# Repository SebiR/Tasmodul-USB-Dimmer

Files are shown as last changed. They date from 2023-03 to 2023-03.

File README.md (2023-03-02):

# Tasmodul USB-Dimmer
A plug-in dimmer for USB powered lamps and lights to be used with Tasmota, WLED or custom ESP8266 firmwares.

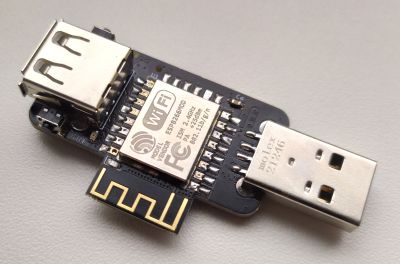
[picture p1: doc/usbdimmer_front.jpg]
Front


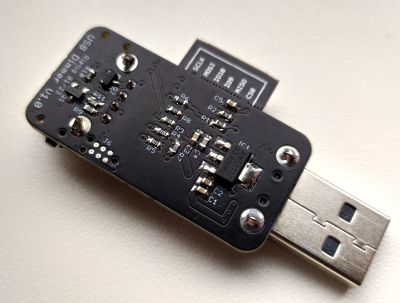
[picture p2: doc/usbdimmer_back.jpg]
Back


## Features
* Small formfactor (21x42mm without USB)
* Up to 2A output current (approx.)
* 2 buttons for user interfacing

## Configuration
* GPIO4: Inverted PWM output (or switch)
* GPIO5: Inverted push button "DOWN"
* GPIO13: Inverted push button "UP"
* GPIO0: Inverted LED indicator

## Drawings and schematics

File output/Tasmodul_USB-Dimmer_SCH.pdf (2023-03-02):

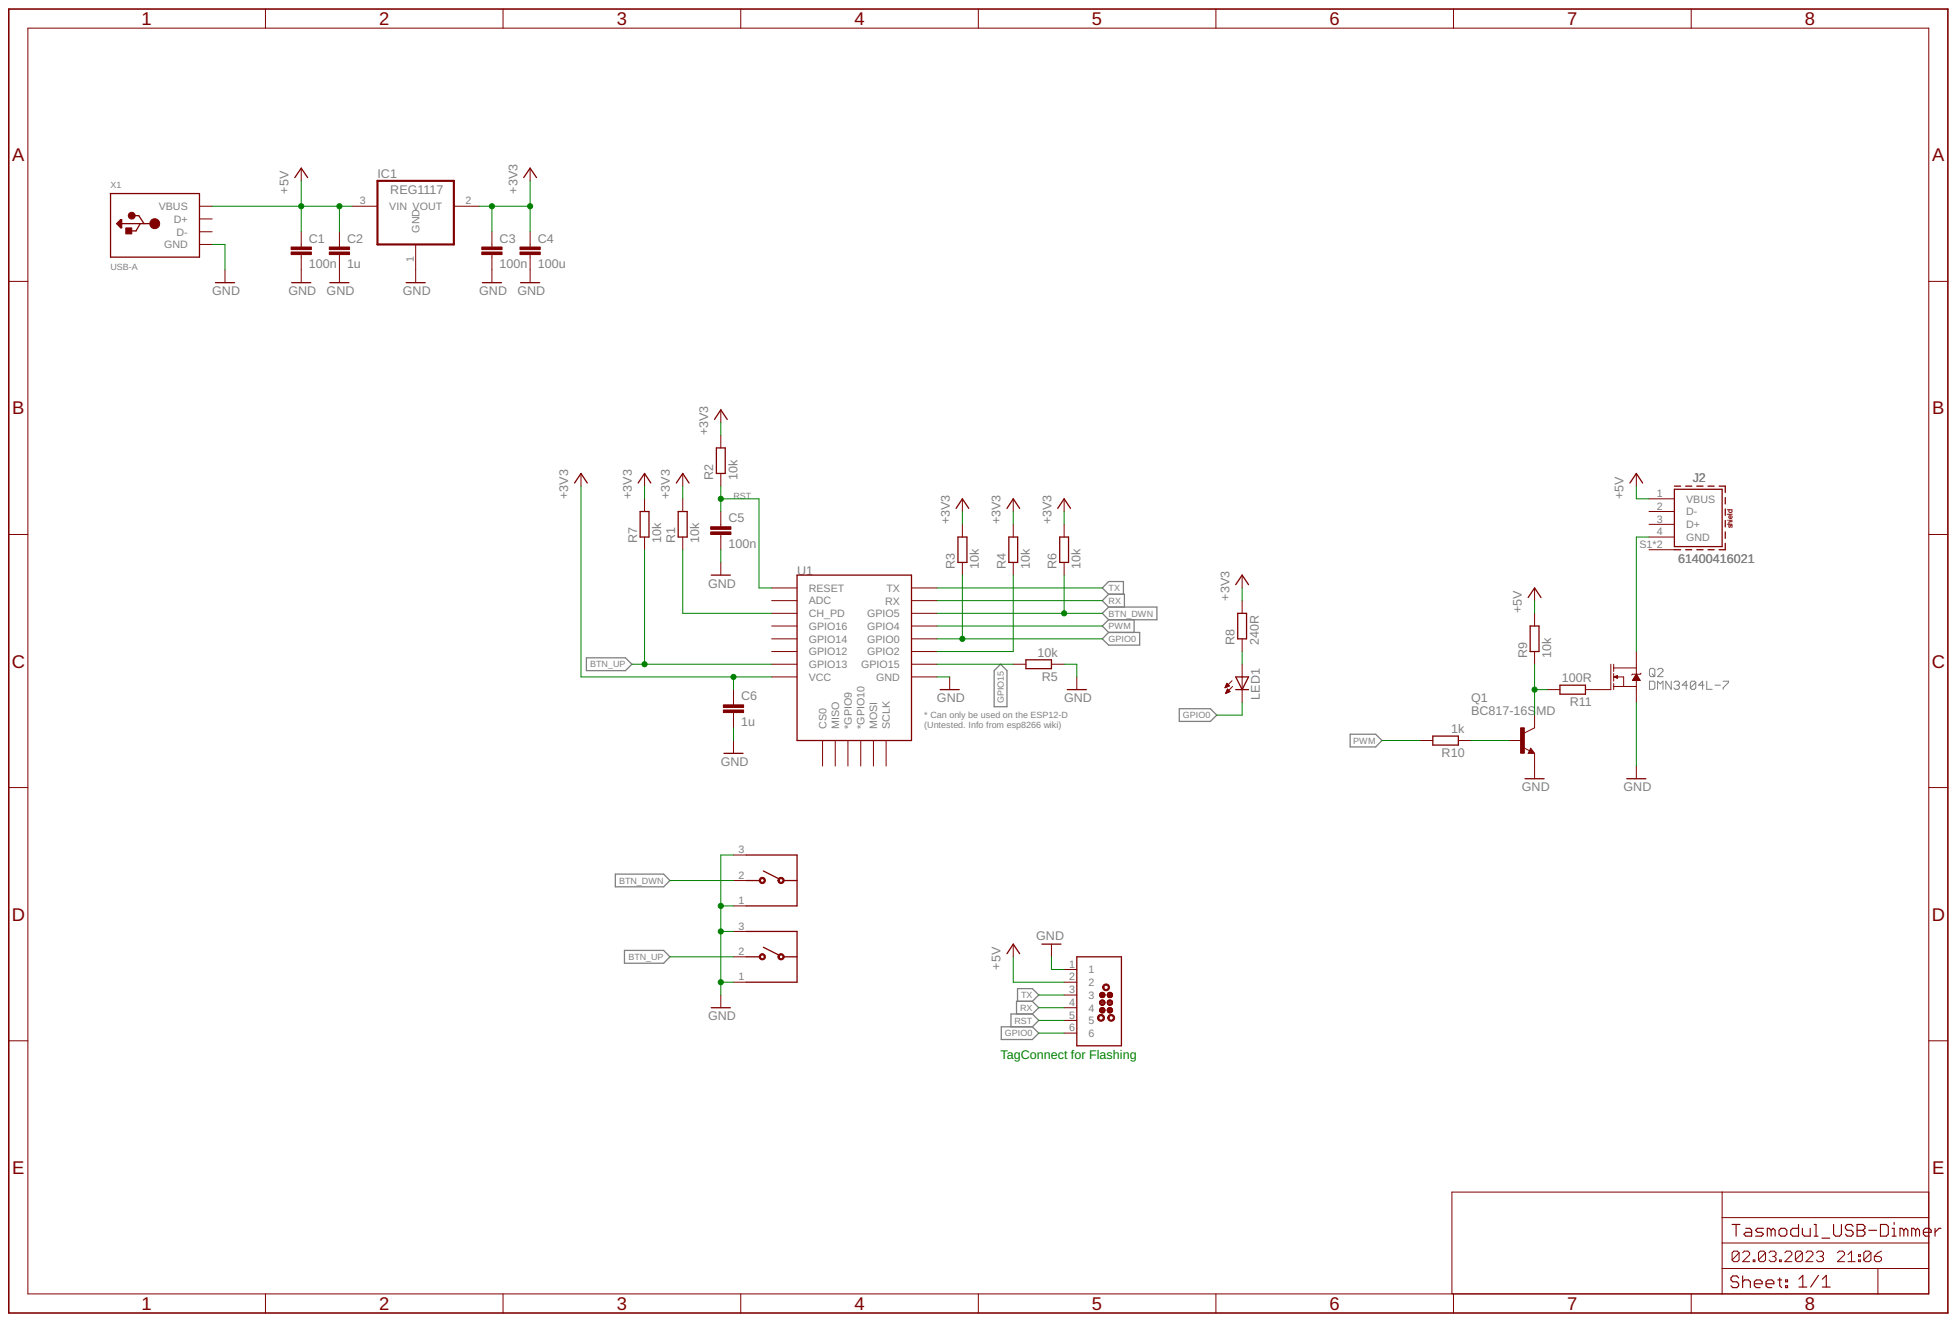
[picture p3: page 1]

* Can only be used on the ESP12-D
(Untested. Info from esp8266 wiki)

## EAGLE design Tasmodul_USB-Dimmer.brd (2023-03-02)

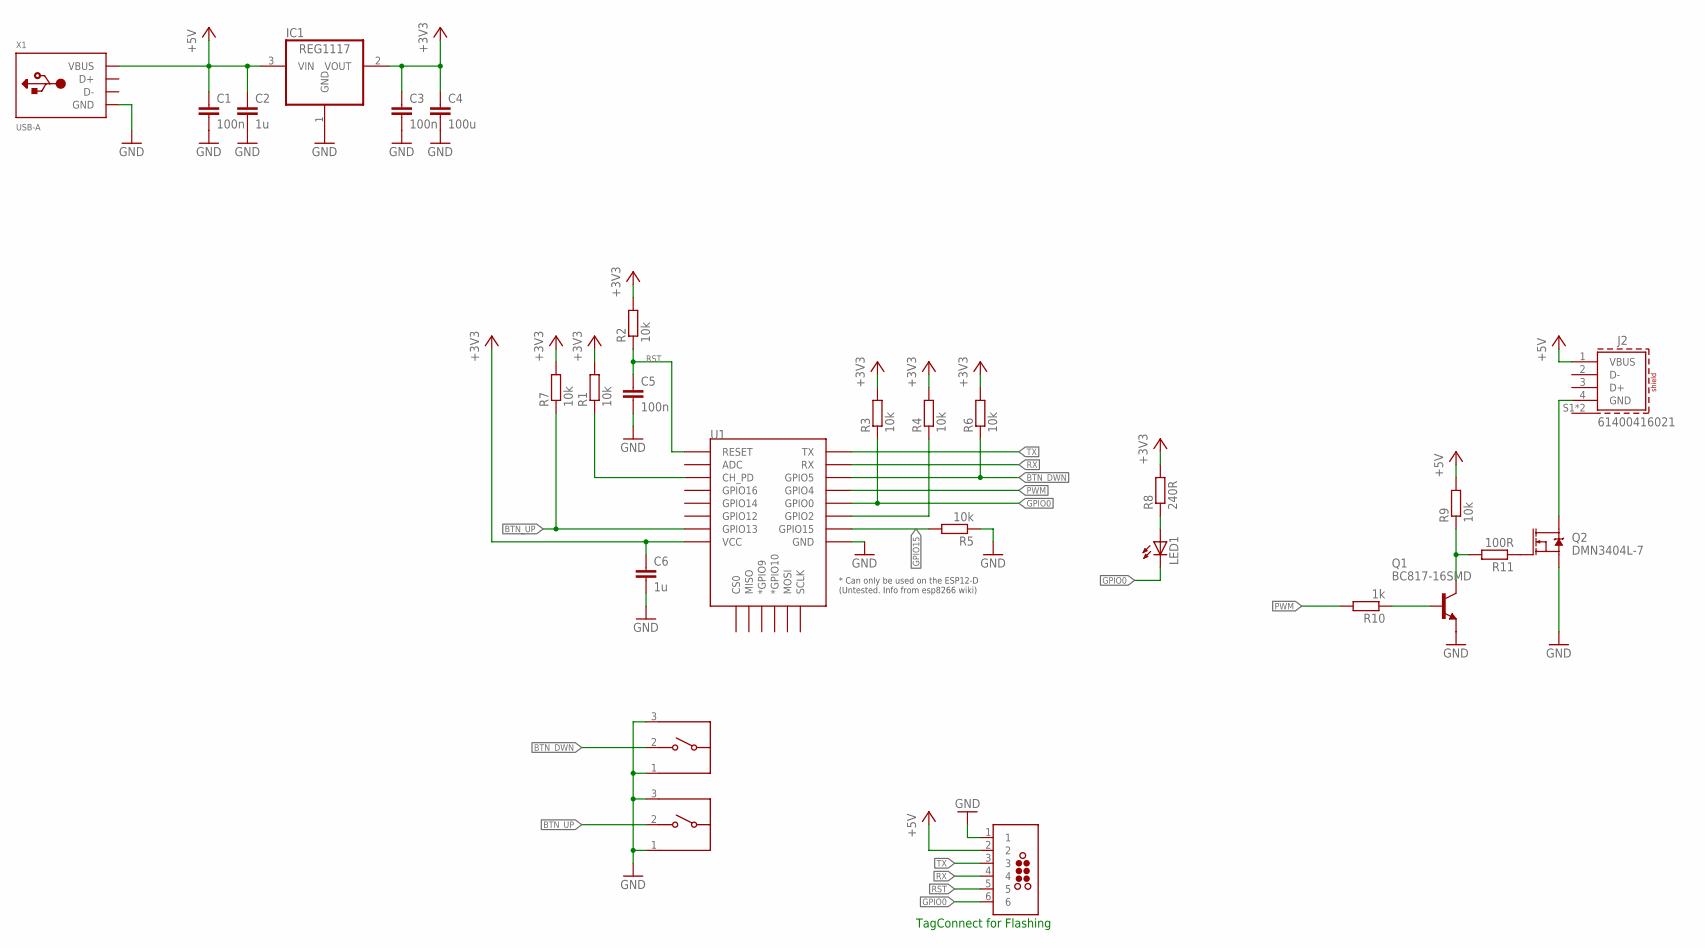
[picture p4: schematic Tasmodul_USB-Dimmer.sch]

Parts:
C1, C3, C5: 100n; C0603
C2, C6: 1u; C0603
C4: 100u; C0603
IC1: REG1117; SOT223
J2: 61400416021
J6: TC2030-MCP-NL
LED1: LEDCHIP-LED0603; CHIP-LED0603
Q1: BC817-16SMD; SOT23-BEC
Q2: DMN3404L-7; SOT23-3
R1, R2, R3, R4, R5, R6, R7, R9: 10k; R0603
R8: 240R; R0603
R10: 1k; R0603
R11: 100R; R0603
S1, S2: 436333033816
U1: ESP12ESMD; ESP12E-SMD
X1: USB-A; MOLEX_480371000

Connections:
+3V3: C3.1, C4.1, C6.1, IC1.2 (VOUT), R1.2, R2.2, R3.2, R4.2, R6.2, R7.2, R8.2, U1.VCC
+5V: C1.1, C2.1, IC1.3 (VIN), J2.1 (VBUS), J6.2, R9.2, X1.1 (VBUS)
BTN_DWN: R6.1, S2.2, U1.GPIO5
BTN_UP: R7.1, S1.2, U1.GPIO13
GND: C1.2, C2.2, C3.2, C4.2, C5.2, C6.2, IC1.1 (GND), J6.1, Q1.E, Q2.2 (S), R5.1, S1.1, S1.3, S2.1, S2.3, U1.GND, X1.4 (GND)
GPIO0: J6.6, LED1.C, R3.1, U1.GPIO0
GPIO15: R5.2, U1.GPIO15
unnamed: LED1.A, R8.1
unnamed: Q2.1 (G), R11.1
unnamed: Q1.B, R10.1
unnamed: R1.1, U1.CH_PD
unnamed: R4.1, U1.GPIO2
unnamed: Q1.C, R9.1, R11.2
unnamed: J2.4 (GND), Q2.3 (D)
PWM: R10.2, U1.GPIO4
RST: C5.1, J6.5, R2.1, U1.RESET
RX: J6.4, U1.RXD0 (RX)
TX: J6.3, U1.TXD0 (TX)

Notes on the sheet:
TagConnect for Flashing

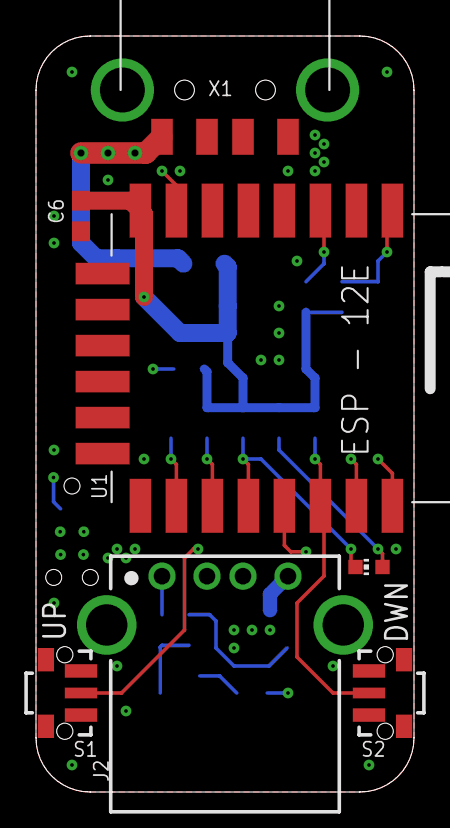
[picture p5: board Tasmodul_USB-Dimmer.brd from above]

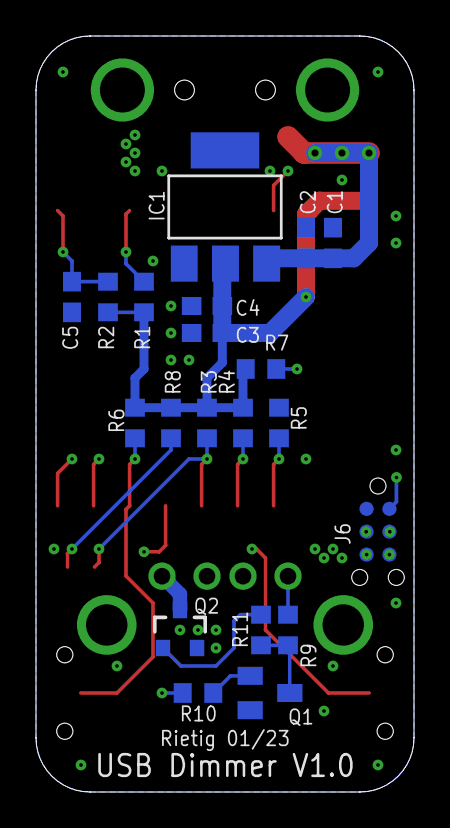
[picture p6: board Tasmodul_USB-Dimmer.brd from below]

Board: 4 copper layers, 21.0 x 42.0 mm, 27 parts (20 on the bottom side), 18 nets.

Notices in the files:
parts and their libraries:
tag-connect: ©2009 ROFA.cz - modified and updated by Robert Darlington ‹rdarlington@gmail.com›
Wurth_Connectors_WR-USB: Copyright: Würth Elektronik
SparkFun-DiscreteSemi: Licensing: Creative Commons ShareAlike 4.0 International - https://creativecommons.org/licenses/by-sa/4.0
